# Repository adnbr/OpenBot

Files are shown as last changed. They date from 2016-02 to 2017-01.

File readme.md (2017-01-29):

# OpenBot

For more information: 
https://wiki.leedshackspace.org.uk/wiki/Projects/OpenBot

Runs Arduino code on a NodeMCU ESP-12 dev board for future proofing - 
hackspace members will be able to modify the device without too much 
trouble as it is standard hardware. 

This is also the reason we are using ThingSpeak instead of a custom 
server install in the space - sometimes things can get a bit 
complicated for people not in the know.

## Software

Rename "keys_example.h" to "keys.h" and fill in the appropriate fields 
before compiling.

### Additional Libraries

* [ESP8266](https://github.com/esp8266/Arduino) - "ESP8266" in Library 
Manager
* [TimeZone](https://github.com/JChristensen/Timezone)
* [Time](https://github.com/PaulStoffregen/Time)

## Hardware

Schematic and PCB created in KiCad.

Gerbers as submitted to OSHPark are available in the gerbers folder 
(just upload the zip.) 
If you don't want to make any changes you can order 
[directly from them](https://oshpark.com/shared_projects/XAhVpFpk).

## Housing

The front panel was machined by 
[Schaeffer AG](http://www.schaeffer-ag.de/) and designed using Front 
Panel Designer (FPD). The design is also available in SVG and DXF 
formats (exported from FPD) both with and without reference points in 
the hope that they might be useful. They are handy in that the text 
output is in the form of a single, clean path.

## What does it look like?

The Current OpenBot

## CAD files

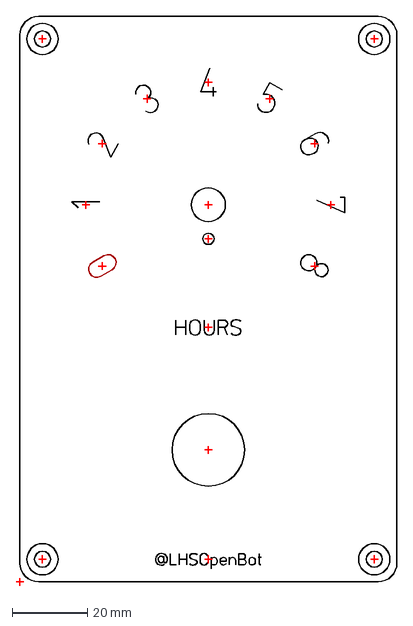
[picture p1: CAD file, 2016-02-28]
housing/faceplate/openbot-front-ref.dxf
101.0 x 151.0 mm

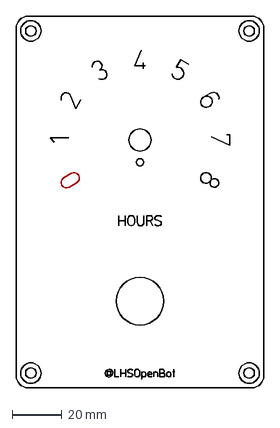
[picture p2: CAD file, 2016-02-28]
housing/faceplate/openbot-front.dxf
100.0 x 150.0 mm

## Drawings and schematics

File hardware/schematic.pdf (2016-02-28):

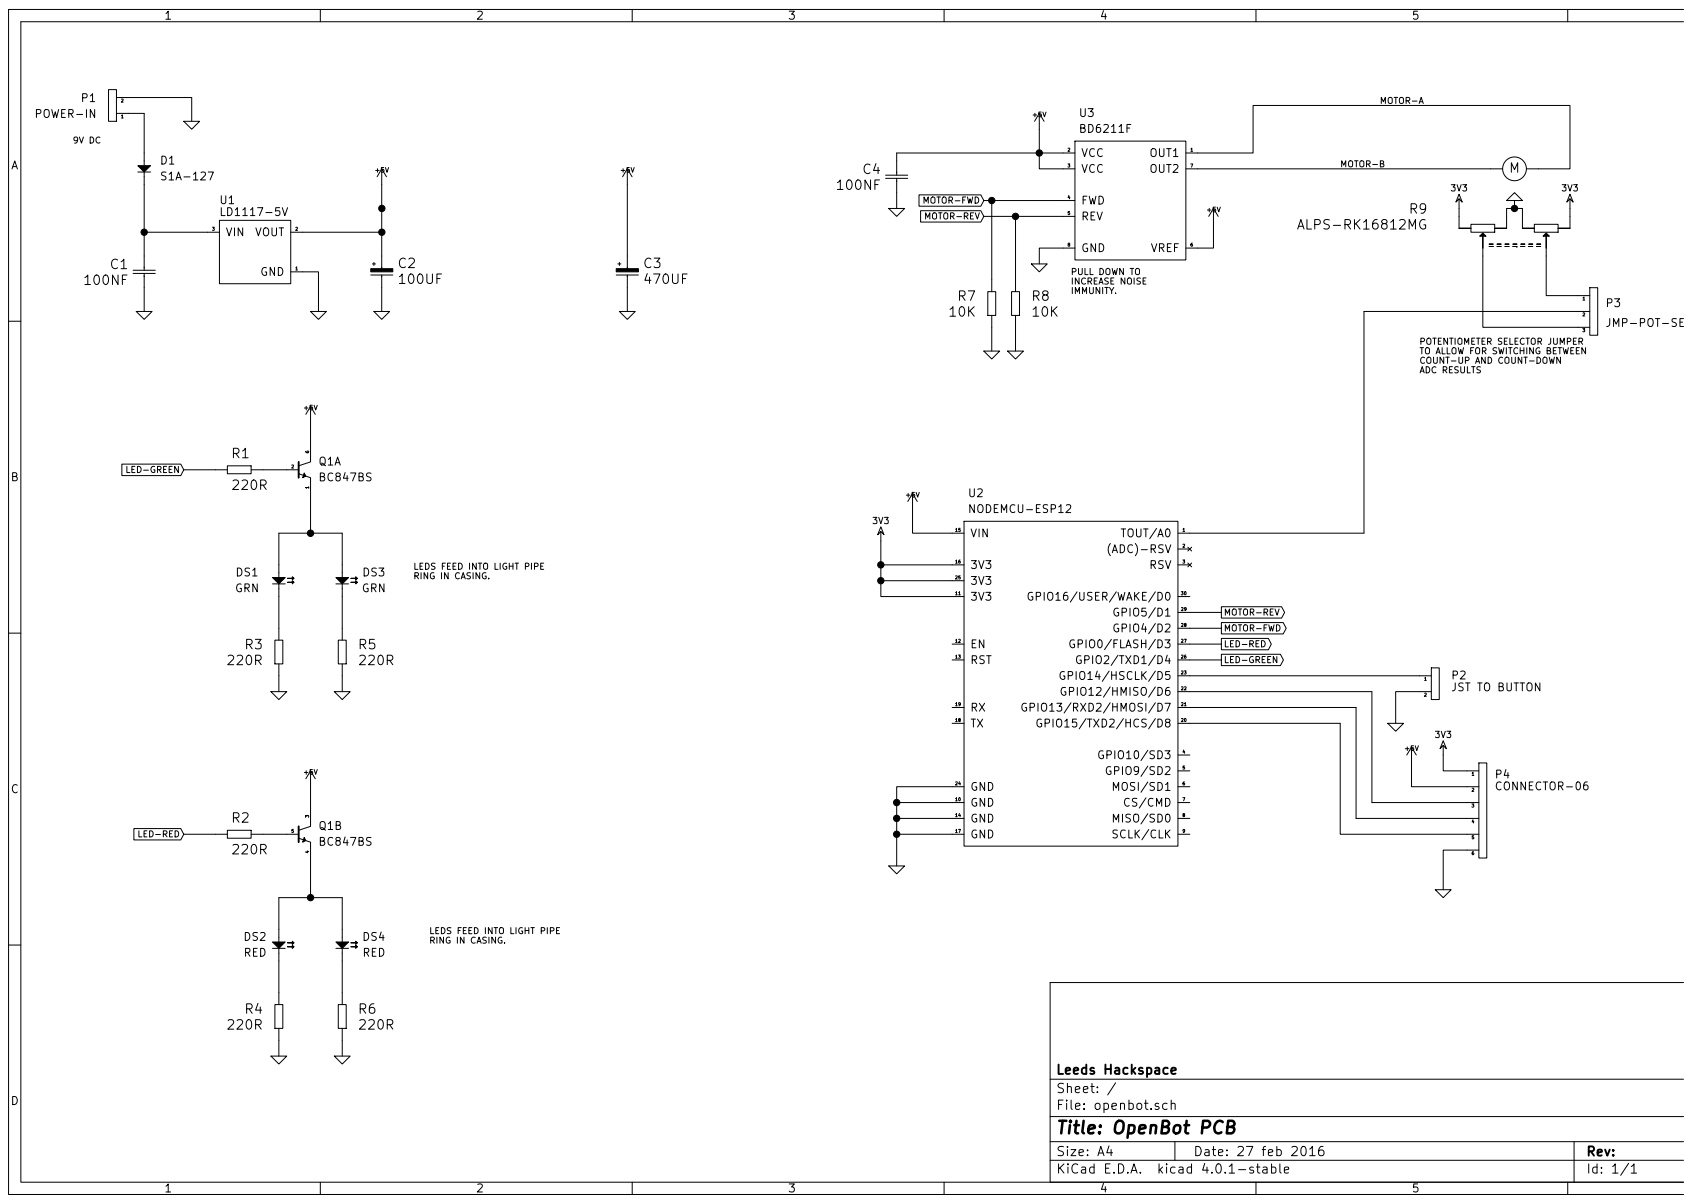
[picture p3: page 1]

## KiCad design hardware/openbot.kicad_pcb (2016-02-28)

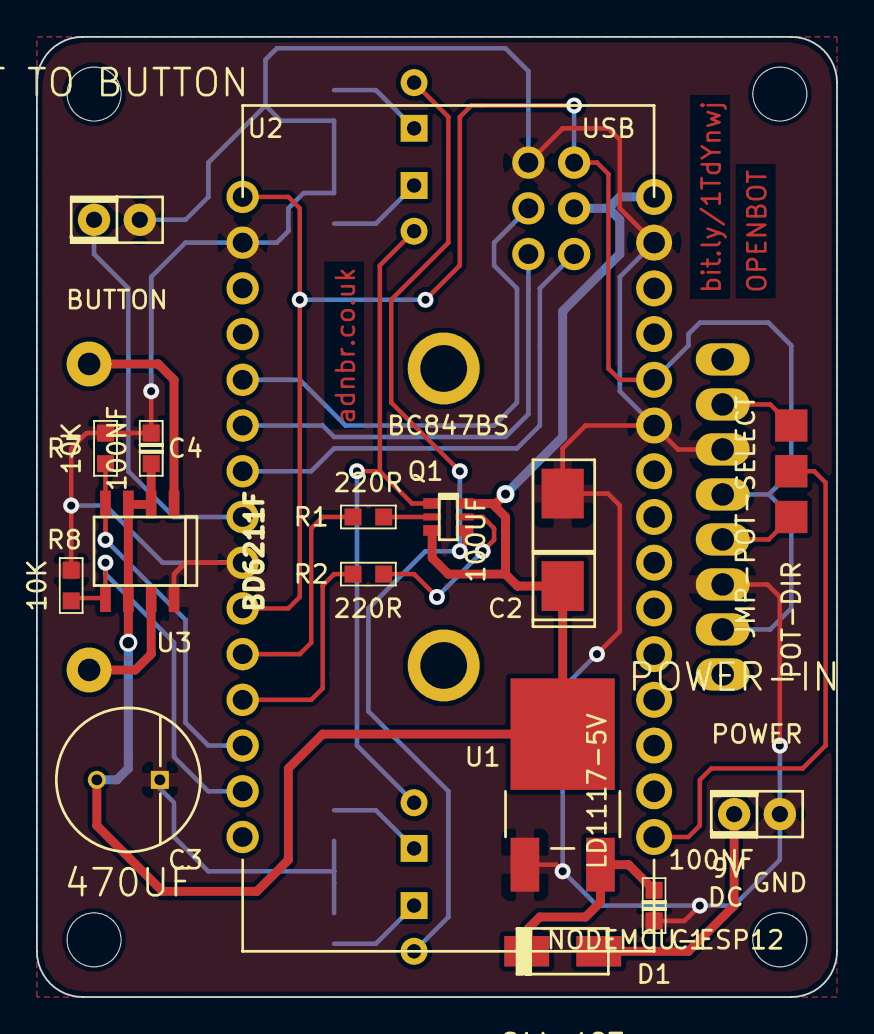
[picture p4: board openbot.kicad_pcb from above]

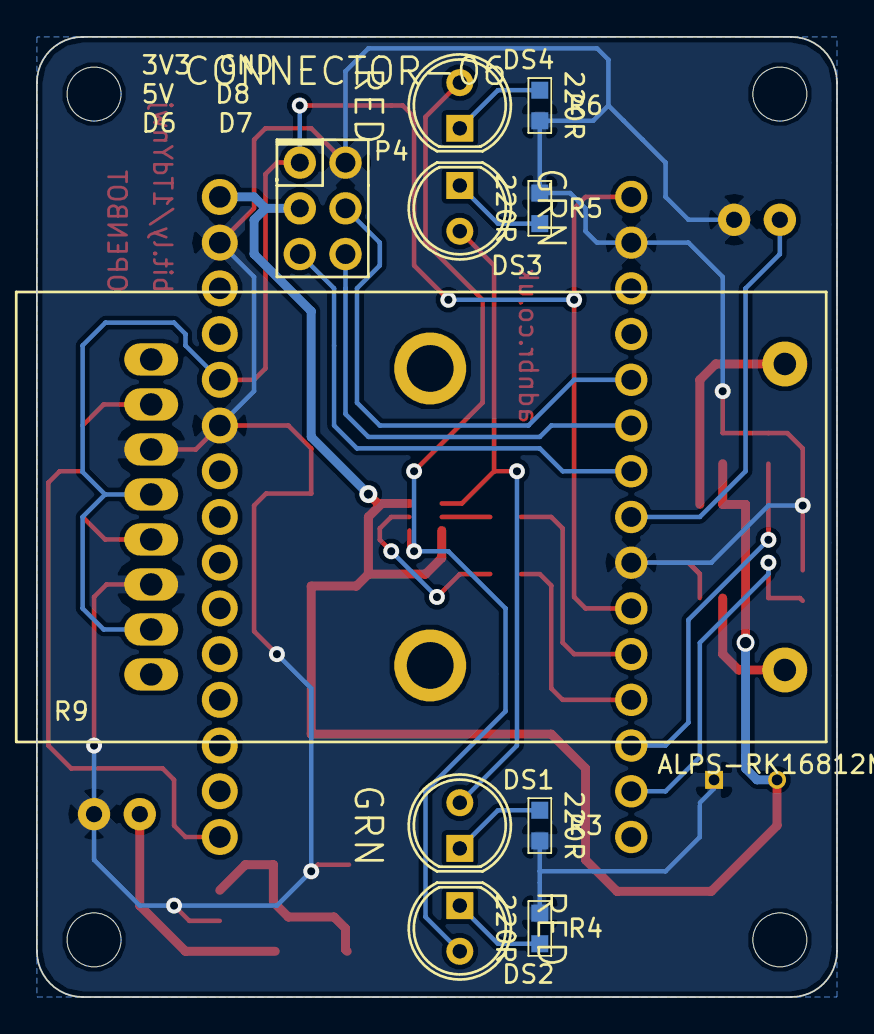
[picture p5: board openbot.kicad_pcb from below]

Board: 2 copper layers, 44.4 x 53.3 mm, 30 parts (10 on the bottom side), 26 nets.

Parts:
BUTTON: JST TO BUTTON; CONN-02
C1, C4: 100NF; CAPACITOR-NP-0603-REFLOW
C2: 100UF; CAP_POL_KEMET_C
C3: 470UF; CAPACITOR-POL-D_8MMxP_3.5MM
D1: S1A-127; DIODE-SMA
DS1, DS3: GRN; LED-5MM
DS2, DS4: RED; LED-5MM
M3-HOLE, M3-HOLE#2, M3-HOLE#3, M3-HOLE#4: VAL**; M3-HOLE
P4: CONNECTOR-06; CONN-06-2x3
POT-DIR: JMP-POT-SELECT; SJ-03
POWER: POWER-IN; CONN-02
Q1: BC847BS; SOT363
R1, R2, R3, R4, R5, R6: 220R; RESISTOR-0603-REFLOW
R7, R8: 10K; RESISTOR-0603-REFLOW
R9: ALPS-RK16812MG; ALPS-RK16812MG-10kBx2
U1: LD1117-5V; TO-252
U2: NODEMCU-ESP12; NODEMCU-DEVKIT
U3: BD6211F; SOP-8

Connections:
3V3: P4.1, R9.A1, R9.B3, U2.11, U2.16, U2.25
+5V: C2.A, C3.A, C4.2, P4.2, Q1.3, Q1.6, U1.2, U2.15, U3.2, U3.3, U3.6
/MOTOR-A: R9.MB, U3.1
/MOTOR-B: R9.MA, U3.7
GND: BUTTON.2, C1.1, C2.C, C3.C, C4.1, P4.6, POWER.2, R3.1, R4.1, R5.1, R6.1, R7.1, R8.1, R9.A3, R9.B1, U1.1, U2.10, U2.14, U2.17, U2.24, U3.8
LED-GREEN: R1.2, U2.26
LED-RED: R2.2, U2.27
MOTOR-FWD: R7.2, U2.28, U3.4
MOTOR-REV: R8.2, U2.29, U3.5
unnamed: POT-DIR.2, U2.1
unnamed: POT-DIR.3, R9.B2
unnamed: POT-DIR.1, R9.A2
unnamed: D1.A, POWER.1
unnamed: P4.3, U2.22
unnamed: P4.4, U2.21
unnamed: Q1.5, R2.1
unnamed: Q1.2, R1.1
unnamed: C1.2, D1.C, U1.3
unnamed: P4.5, U2.20
unnamed: DS2.C, R4.2
unnamed: DS4.C, R6.2
unnamed: DS1.A, DS3.A, Q1.1
unnamed: BUTTON.1, U2.23
unnamed: DS1.C, R3.2
unnamed: DS3.C, R5.2
unnamed: DS2.A, DS4.A, Q1.4

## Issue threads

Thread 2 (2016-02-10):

Handle no NTP result cleanly

adnbr, 2016-02-10:
If the primary or secondary NTP result cannot be resolved switch to a  version of the tweets that don't include the closing time.

Closed 2016-02-28.

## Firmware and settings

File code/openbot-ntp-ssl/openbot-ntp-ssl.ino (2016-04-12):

/*
 *  Leeds Hackspace OpenBot
 *  Tweets (@LHSOpenBot) when the space is open for non-keyholders.
 *  For more information ask Aidan, or check the wiki. Flash onto an ESP-12E/NodeMCU dev board.
 *
 *  Set up Wifi/API credentials in keys.h.
 *  Alter tweeted text in strings.h.
 *
 *  Thingspeak channel fields:
 *
 *  +-------+-------+---------+-----------+
 *  | #1    | #2    | #3      | #4        |
 *  +-------+-------+---------+-----------+
 *  | hours | until | message | localutc  |
 *  +-------+-------+---------+-----------+
 *
 *  http://www.leedshackspace.org.uk
 *  CC-BY-SA 2016
 *
 */

#include <ESP8266WiFi.h>
#include <WiFiClientSecure.h>
#include <TimeLib.h>
#include <Timezone.h>
#include <EEPROM.h>

#include "keys.h"
#include "strings.h"
#include "LocalNTP.h"
#include "motor.h"

#define PIN_LED_RED        D3
#define PIN_LED_GREEN      D4
#define PIN_BUTTON         D5
#define PIN_MOTOR_FWD      D1
#define PIN_MOTOR_REV      D2
#define KNOB_VARIANCE      3 // +/- ideal knob position.

#define EEPROM_ADDRESS     0
#define EEPROM_OK          255

//const char* ntpServerName = "time.nist.gov";
const char* ntpServerName = "uk.pool.ntp.org";
#define NTP_UPDATE_FREQ    21700

// United Kingdom (London, Belfast, Edinburgh)
TimeChangeRule SummerTime = {"BST", Last, Sun, Mar, 1, 60};          // British Summer Time
TimeChangeRule StandardTime = {"GMT", Last, Sun, Oct, 2, 0};         // Greenwich Mean Time

// Set the timezone to allow for automatic DST updates.
Timezone TZ(SummerTime, StandardTime);

time_t closingTime;
unsigned long lastChecked;
static WiFiClientSecure client;

bool spaceStateOpen = false;

LocalNTP ntp;
motor knob(PIN_MOTOR_FWD, PIN_MOTOR_REV);

void connectWifi() 
{
  // Turn on the WiFi and connect using the credentials in the keys file.
  Serial.println("Connecting to '" + String(ssid) + "'");
  WiFi.mode(WIFI_STA);
  WiFi.begin(ssid, pass);

  // Wait for a connection to be made, then print out the IP address.
  while (WiFi.status() != WL_CONNECTED) {
    delay(200);
    Serial.print(".");
  }
  Serial.print("\nConnected to '" + String(ssid) + "' with IP: ");
  Serial.println(WiFi.localIP());
}

void disconnectWifi() 
{
  Serial.println("Disconnecting from Wifi");
  WiFi.disconnect();
}


time_t ntpUpdate()
{
  time_t updateTime = ntp.getNtpTime();
  if (updateTime != 0) {
    setTime(TZ.toLocal(updateTime));
    Serial.println("Current local time is: " + displayTime(hour(), minute()));
    return (updateTime);
  } else {
    return 0;
  }
}

String generateHttpRequest(int hours, time_t closing, String message, bool tweet = false) 
{
  // Write the closingTime out to a string, and submit it to ThingSpeak. If NTP failed, send a message
  // to the 
  String closingTimeString = "#ntpfailure";
  if (closingTime != 0) {
    closingTimeString = displayTime(hour(closing), minute(closing));
  } 
  
  // Construct the actual data to be transmitted - includes the dial number,
  // expected closing time and the message itself.
  String data = String("field1=") + hours +
                       "&field2=" + closingTimeString +
                       "&field3=" + message +
                       "&field4=" + now(); //Second since Jan 1st 1970

  // If tweet string is not empty.
  if (tweet) {
    data = data + "&twitter=" + api_twitter_feed + "&tweet=" + message;
  }

  // Construct the HTTP header to be sent, and append the data.
  return String("POST ") + api_uri + " HTTP/1.1\r\n" +
               "Host: " + api_host + "\r\n" +
               "THINGSPEAKAPIKEY: " + api_key + "\r\n" +
               "Content-Type: application/x-www-form-urlencoded\r\n" +
               "Content-Length:"  + data.length() + "\n\n" + data;

}

String displayTime(short hour, short minute) 
{
  String output;
  if (hour < 10) {
    output = "0";
  }
  output = output + hour + ":";
  if (minute < 10) {
    output = output + "0";
  }
  output = output + minute;
  return output;
}

long generateClosingTime (int hours) 
{
  long closing = now();
  
  int adjustHours = (hours - 1) * 3600;
  int adjustMinutes = 3600 - (60 * (minute() - (minute() - (minute() % 15))));
  closing += adjustHours + adjustMinutes;

  return closing;
  
}

float generateKnobAnalogValue (time_t closing) 
{
  float floatAnalogValue = 0.0f;
  int analogValue = 0;
  if (closing != 0) {
    floatAnalogValue = (closing - now()) / 3600.0f;
    Serial.println (String(closing) + " - " + now() + " = " + (closing - now()));
    Serial.println(floatAnalogValue);
    analogValue = round(floatAnalogValue);
    Serial.println(analogValue);
    analogValue = analogValue * 128 + 72;
  } else {
    analogValue = 72;
  }
  return analogValue;
}

String generateMessage (int hours, time_t closing) {
  String message;
  int randomNumber;
  if (hours == 0) {
    // 0/closed has been selected on the dial. Tweet a "random" closed message.
    randomNumber = random (1, numberClosedStrings);
    message = messageCloseSpace[randomNumber].leader;

    // Check for closingTime having a value - an empty closing time indicates that
    // the time couldnot be retrieved. Append the current time if it's OK.
    if (closing != 0) {
      message = message  + " (It's " + displayTime(hour(), minute()) + ")";
    } else {
      message = message + " #ntpfailure";
    }
    
    return message;
        
  } else {
    
    // Space is open. Tweet a "random" open message.
    randomNumber = random (1, numberOpenStrings);
    // If the hour is singular "1" then we need to use the singular text. Otherwise, add the
    // number and append "hours".
    if (hours == 1) {
      message = messageOpenSpace[randomNumber].leader + messageOpenSpace[randomNumber].singular + messageOpenSpace[randomNumber].punctuation;
    } else {
      message = messageOpenSpace[randomNumber].leader + hours + " hours" + messageOpenSpace[randomNumber].punctuation;
    }

    // Check for empty closing time again, append the time if it's OK, ntpfailure if it's not.
    if (closing != 0) {
      message = message + " (Until ~" + displayTime(hour(closing), minute(closing)) + ")";
    } else {
      message = message + " #ntpfailure";
    }
    
    return message;
    
    
  } // End if hours = 0
  
}

bool moveKnob(int targetPos) {

  int currentPos = analogRead(A0);
  char motorDirection;

  while (!(abs(currentPos - targetPos) <= KNOB_VARIANCE)) {
    // Not there yet. Move that knob!
    if (currentPos > targetPos) {
      knob.moveMotor(COUNTERCLOCKWISE);
      Serial.println("CCW - " + String(currentPos) + "/" + String(targetPos));
    } else {
      knob.moveMotor(CLOCKWISE);
      Serial.println(" CW - " + String(currentPos) + "/" + String(targetPos));
    }
    currentPos = analogRead(A0);
  } 
  knob.moveMotor(STOP);
  
}

bool sendHttpRequest(String httpRequest, int hours) {


    // Try and connect to the API host. Restart at 5x failures.
    int failCount = 0;

    while (!client.connect(api_host, api_port)) {
      failCount++;
      Serial.println("Connection to '"+ String(api_host) + ":" + String(api_port) + "' failed on attempt " + String(failCount) + ". Waiting 1 second to retry.");
      delay(1000);
      if (failCount > 5) {
        return false;
      }
    }

    // Check the certificate hash.
    if (!client.verify(api_cert_hash, api_host)) {
      Serial.println("Certificate doesn't match.");
      return false;
    }

    // Send the HTTP Request to the server.
    client.print(httpRequest);

    Serial.println("Sending HTTP Request:");
    Serial.println(httpRequest);
    Serial.print("\n\n");

    // Wait for max 8 seconds for reply, otherwise exit.
    unsigned long timeout = millis() + 8000;
    while (!client.available()) {
      if (timeout - millis() < 0) {
        Serial.println("Client Timeout.");
        client.stop();
        return false;
      }
    }

    Serial.println("Received from server:");
    while(client.available()){
      Serial.print(client.readStringUntil('\r'));
    }
    Serial.print("\n\n");

    // Close the connection, we're done here.
    Serial.println("Closing connection with '" + String(api_host) + "'");
    client.stop();



    return true;

}

bool transmitMessage(int hours) {

 // Write the hours value to the eeprom to allow for recovery should the SSL handshake
 // crash the device (sometimes this happens thanks to low/fragmented memory.)
 Serial.println("Writing check value to EEPROM");
 eepromWriteCheckValue(hours);

     
  if (ntpUpdate()) {
    // Generate the closing time.
    Serial.println("NTP is OK. Generating closing time.");
    closingTime = generateClosingTime(hours);
  } else {
    Serial.println("No NTP.");
    closingTime = 0;
  }

 // Construct a message using the hours data, then generate the HTTP request.
 String message = generateMessage(hours, closingTime);
 String request = generateHttpRequest(hours, closingTime, message, true);

 Serial.println(message);
 Serial.println(request);

 bool messageSent = sendHttpRequest(request, hours);

 // If we've got to here then the message has probably gone through, nothing
 // more we can do on our end.
 if (messageSent) {
  eepromWriteCheckValue(EEPROM_OK);
   Serial.println("Check value cleared from EEPROM.");
   return true;
 } else {
   return false;
 } 
}

void eepromWriteCheckValue(int value) {

  byte lowByte = ((value >> 0) & 0xFF);
  EEPROM.write(EEPROM_ADDRESS, lowByte);
  EEPROM.commit();

}

unsigned int eepromReadCheckValue() {

  byte lowByte = EEPROM.read(EEPROM_ADDRESS);
  return lowByte;

}

bool setSpaceStatus(int hours) {
    // If the hours was 0, disconnect the wifi. Space is closed or NTP failed so not needed anymore.
    if (hours == 0 || closingTime == 0) {
      disconnectWifi();
      spaceStateOpen = false;
    } else {
      spaceStateOpen = true;
    }
    return spaceStateOpen;
}


void setup() 
{

  pinMode(PIN_BUTTON, INPUT);
  pinMode(PIN_MOTOR_FWD, OUTPUT);
  pinMode(PIN_MOTOR_REV, OUTPUT);

  knob.moveMotor(STOP);
  
  EEPROM.begin(128);
  Serial.begin(115200);
  Serial.println("\n\nStarting OpenBot...");

  // Connect to the Wifi & get the time.
  connectWifi();
  
  // Refresh the NTP server details.
  // Get the IP address of the NTP servers.
  IPAddress ntpServerIP;
  Serial.println("Looking up NTP Server (" + String(ntpServerName) + ")");
  bool noIP = false;
  while (!noIP) {
    noIP = WiFi.hostByName(ntpServerName, ntpServerIP);
  }
  
  ntp.setNtpIP(ntpServerIP);

  unsigned int checkValue = eepromReadCheckValue();
  if (checkValue <= 8) {
    
    // The device has rebooted before completing the submission. Is there an internet error?
    Serial.println("Uncompleted submission detected. Resending value '" + String(checkValue) + "'.");
    if (ntpUpdate()) {
      // Generate the closing time.
      Serial.println("NTP is OK. Generating closing time.");
      closingTime = generateClosingTime(checkValue);
    } else {
      Serial.println("No NTP.");
      closingTime = 0;
    }
    
    transmitMessage(checkValue);
    setSpaceStatus(checkValue);
    
  } else {

    // We are just booting normally. Grab the time from NTP to prove the connection works.
    ntpUpdate();
  }
  
  // Disconnect from the wifi.
  disconnectWifi();
  
}

void loop() {

  // Is button pressed?
  if (digitalRead(PIN_BUTTON) == LOW) {
    
    // Yes, button was pressed
    // Read the ADC value, divide into 8 and round to get the number of hours indicated.
    short knobValue = analogRead(A0);
    short hours = floor(knobValue / 128);
    Serial.println("Raw knob value: " + String(knobValue) + "\tHours value: " + hours);

    // Connect to the wifi & update the time from NTP. 
    // This wifi connection will be maintained for hours specified by the knob.
    connectWifi();

    // Transmit the message to Thingspeak & Twitter
    int failCount = 0;
    while (!transmitMessage(hours)) {
      failCount++;
      Serial.println("Couldn't transmit. Disconnecting Wifi, waiting 1 second & trying again.");
      disconnectWifi();
      delay(1000);
      connectWifi();
      if (failCount > 5) {
        ESP.restart();
        // Superstition says that this is required sometimes to make the ESP reboot cleanly.
        delay(1000);
      }
    }

    // Move the knob.
    int requiredKnobValue = generateKnobAnalogValue(closingTime);

    Serial.println("Required Analog Knob Value: " + String(requiredKnobValue));
    
    moveKnob(requiredKnobValue);

    setSpaceStatus(hours);
      
  } else {
    // No, button wasn't pressed.
    if (spaceStateOpen && millis() - lastChecked > 15000) {
      // Move the knob as required.
      int requiredKnobValue = generateKnobAnalogValue(closingTime);
      moveKnob(requiredKnobValue);
      
      // If the time is 15 minutes before the anticipated closing time disconnect the wifi
      // and set the status to closed. This gives time for Marvin (the space controller)
      // to close the space on time - it takes 15 minutes for a wifi device's presence to decay.

      int preClosingMinute = minute(closingTime) - 15;

      if (preClosingMinute < 0) {
        preClosingMinute += 60;
      }
      
      if (round((closingTime - now()) / 3600.0f) == 0 && minute() == preClosingMinute) {
        disconnectWifi();
        spaceStateOpen = false;
        Serial.println("Space Status: Closed");
      }
      lastChecked = millis();
    } // End if space status open     
  }
}

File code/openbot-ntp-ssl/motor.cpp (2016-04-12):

#include "motor.h"

motor::motor (char pinClockwise, char pinCounterclockwise) 
{
  clockwisePin = pinClockwise;
  counterclockwisePin = pinCounterclockwise;
}


// TODO: Convert this into an array. 
void motor::moveMotor(char motorDirection) {
  
  char clockwiseState, counterclockwiseState;
  switch (motorDirection) {
    case CLOCKWISE:
      clockwiseState = HIGH;
      counterclockwiseState = LOW;
      break;
    case COUNTERCLOCKWISE:
      clockwiseState = LOW;
      counterclockwiseState = HIGH;
      break;
    case STOP:
      clockwiseState = LOW;
      counterclockwiseState = LOW;
      break;
  }
  digitalWrite(clockwisePin, clockwiseState);
  digitalWrite(counterclockwisePin, counterclockwiseState);

}

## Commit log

2016-02-01 DIV/0
    Can't divide by zero, duh.
    Will now properly write the EEPROM check value before attempting to POST
    and clear it on completion. This allows the device to try resubmitting
    if an unexpected reset occurs (perhaps a memory & SSL related crash.)
    More generic NTP pool address.
    moveKnob timer fix. Knob motor not currently wired in, needs H-bridge.
    Removed some duplicated code.
    Added serial debugging for knob values.
    [openbot-ntp-ssl.ino]
2016-02-03 NTP, motor, space
    Added a backup NTP server - redundancy if the pool doesn't respond.
    Disabled the motor loop. There's currently no motor attached (no H
    bridge) so the while loop would have become stuck.
    Added missing space in space is closed strings.
    [openbot-ntp-ssl.ino]
2016-02-10 NTP should now fail gracefully.
    Untested on device, but if the time is not flagged as "set" then the
    tweet won't include an estimated closing time and will include
    #ntpfailure
    [openbot-ntp-ssl.ino]
2016-02-19 Fixed NTP failure mode.
    [openbot-ntp-ssl.ino]
2016-02-20 Local time update fix
    Local time was only updated every time the clock was refreshed from NTP.
    Now updates every 30 seconds (with the motor check) and immediately
    prior to tweet submission.
    [openbot-ntp-ssl.ino]
2016-02-27 Pin changes, hardware, housing added to git
    KiCad schematic & PCB. First revision.
    Housing faceplate files (FPD, SVG and DXF formats)
    Code update to reflect pin changes in hardware
    [openbot-front-ref.dxf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]
2016-02-28 Schematic & Datasheets
2016-03-21 Motorised potentiometer turning
    Ticks down hours. Should probably test over a midnight period.
2016-04-12 Rewrite
    - Time handling rewritten to work better with after-midnight times.
    - Disconnects from WiFi when the space is "closed" to allow Marvin to
    close the space
    - Additional strings
    - motor knob turns halfway between hours, turning to zero 30 minutes
    before closing.
    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
2017-01-29 Schematic & PCB work.
